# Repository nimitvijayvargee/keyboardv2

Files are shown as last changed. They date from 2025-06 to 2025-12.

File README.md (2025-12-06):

# keyboardv2

A second version of my original keyboard I designed during Hackpad V2. This keyboard follows a slight variation of the ANSI-75 Layout and is coded with QMK and and customizable with VIAL.
The keyboard deviates from my original design by implementing RGB and embracing the plate-less design. The keyboard has per-key RGB thanks to the SK6812-Mini-e Inverted LED.


## Keyboard in VIAL


## Keyboard Case


## Section of keyboard routing near the microcontroller


## KLE viewer of the keyboard (ANSI-75)


## PCB Render


## All together!


# Note about the case V2 design
The new design was designed differently from the rest of the keyboard for Blueprint. It fixes some of my issues with the previous design, mainly the size and the thickness. This design is a bit more fragile, but unless you absolutely destroy your keyboard at 400WPM, it should hold. The USB port design is also slightly tighter, but unless you are using a USB cable thicker than the MCU itself, you should be fine. The other changes are the screw holes having chamfering to prevent snapping off under pressure, and the tolerances being increased to be 3D printed better.

# Bill of Materials (for highway)
| Item | Cost(INR) | Cost(USD) |
|---|---|---|
| PCBA | 6460 | 75 |
| Switches | 2800 | 33 |
| Keycaps | 1300 | 15 |
| Rotary Encoder, Threaded Inserts, M3x6 Screws, Adhesive Grips | 1500 | 18 |
| Stabilizers | 1000 | 13 |
| Case (Printing Legion) | N/A | N/A |
| **Total** | **12060** | **154** |

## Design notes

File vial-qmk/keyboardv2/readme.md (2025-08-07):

# nimits_keyboard_v2

Developed by Nimit Vijayvargee and funded by Hack Club!

* Keyboard Maintainer: [Nimit Vijayvargee](https://github.com/NimitVijayvargee)
* Hardware Supported: RP2040 boards that follow the Pi Pico footprint (i.e Raspberry Pi Pico, Pico H or Pico W/WH)
* Hardware Availability: [Raspberry Pi](https://www.raspberrypi.com/products/raspberry-pi-pico/)

## Bootloader

Enter the bootloader by holding "BOOTSEL" while connecting the device. The device is now in bootloader mode.

## Flashing

After entering bootloader mode, copy and paste generated .uf2 (binary) file into USB Mass storage drive labelled "RPI-RP2". The device will now reconnect with the newly flashed firmware.

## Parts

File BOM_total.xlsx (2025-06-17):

Product/Item | Source | Price (INR) | Price (USD) | Required for | Comment
PCB + Assembly | JLCPCB | N/A | 75 | Main Keyboard | The PCB, you can't build a keyboard without this
Akko V3 Silver Switch (45x2) | Stackskb | 2800 | 32.73 | Switches | Personal Preference, decently priced at 36c/pc.
Keycaps | Stackskb | 1300 | 15.2 | Keycaps | Generic gradient keycaps in white-blue, cherry layout
EC11 Rotary Encoder | Amazon | 1500 | 18 | Encoder | Knob for volume control
M3x6 Threaded Inserts |  |  |  | Mounting | Will be melted into the plastic with my handy soldering iron
Allen style M3x6 Screws |  |  |  | Mounting | Quantity is 300, but lower quantity is more expensive somehow
Grips for case |  |  |  |  | Anti slip adhesive grips to apply to the back of the plastic
Stabilizers | Meckeys | 1000 | 13 | Stabilizers | PCB Mounted
Case | Printing Legion | N/A | N/A | Casing | 3D printed
Total |  |  | 153.93

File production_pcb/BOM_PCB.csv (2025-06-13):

Designator | Qty | Value | DNP | LCSC Part # | Comment | Footprint
A1 | 1 | RaspberryPi_Pico | DNP |  |  | Module:RaspberryPi_Pico_Common_Unspecified
C1,C2,C3,C4,C5,C6,C7,C8,C9,C10,C11,C12,C13,C14,C15,C16,C17,C18,C19,C20,C21,C22,C23,C24,C25,C26,C27,C28,C29,C30,C31,C32,C33,C34,C35,C36,C37,C38,C39,C40,C41,C42,C43,C44,C45,C46,C47,C48,C49,C50,C51,C52,C53,C54,C55,C56,C57,C58,C59,C60,C61,C62,C63,C64,C65,C66,C67,C68,C69,C70,C71,C72,C73,C74,C75,C76,C77,C78,C79,C80 | 80 | 100nF |  | C344189 | 100nF | Capacitor_SMD:C_0402_1005Metric
D1,D3,D4,D5,D6,D7,D8,D9,D10,D12,D13,D14,D15,D16,D17,D18,D19,D20,D21,D22,D23,D24,D25,D26,D27,D28,D29,D30,D32,D33,D34,D35,D36,D37,D38,D39,D40,D41,D42,D43,D44,D45,D46,D48,D49,D50,D51,D52,D53,D54,D55,D56,D57,D58,D59,D60,D62,D64,D65,D66,D67,D68,D69,D70,D71,D72,D73,D74,D75,D77,D80,D81,D82,D83,D84,D85,D87,D88,D89,D93,D94,D96 | 82 | Diode |  | C917030 | 1N4148 | Diode_SMD:D_SOD-123
D97,D99,D100,D101,D102,D103,D104,D105,D106,D108,D109,D110,D111,D113,D114,D115,D116,D117,D118,D119,D120,D121,D122,D123,D124,D125,D126,D128,D129,D130,D131,D132,D133,D134,D135,D136,D137,D138,D139,D140,D141,D142,D144,D145,D146,D147,D148,D149,D150,D151,D152,D153,D154,D155,D156,D158,D160,D161,D162,D163,D164,D165,D166,D167,D168,D169,D170,D171,D173,D176,D177,D178,D179,D180,D183,D184,D185,D189,D190,D192 | 80 | LED_SK6812MINI |  | C5149201 | RGB_LED | SK6812:LED_SK6812-E
H1,H2,H3 | 3 | Mounting_Hole | DNP |  |  | ScottoKeebs_Stabilizer:Stabilizer_MX_2.00u
H4 | 1 | Mounting_Hole | DNP |  |  | ScottoKeebs_Stabilizer:Stabilizer_MX_6.25u
H5,H6,H7,H8,H9 | 5 | Mounting_Hole | DNP |  |  | MountingHole:MountingHole_3.2mm_M3
S1,S3,S4,S5,S6,S7,S8,S9,S10,S12,S13,S14,S15,S17,S18,S19,S20,S21,S22,S23,S24,S25,S26,S27,S28,S29,S32,S34,S35,S36,S37,S38,S39,S40,S41,S42,S43,S44,S45,S48,S50,S51,S52,S53,S54,S55,S56,S57,S58,S59,S60,S64,S66,S67,S68,S69,S70,S71,S72,S73,S74,S75,S80,S89,S93,S94,S96 | 67 | Keyswitch | DNP |  |  | ScottoKeebs_MX:MX_PCB_1.00u
S30 | 1 | Keyswitch | DNP |  |  | ScottoKeebs_MX:MX_PCB_2.00u
S33,S46 | 2 | Keyswitch | DNP |  |  | ScottoKeebs_MX:MX_PCB_1.50u
S49,S77 | 2 | Keyswitch | DNP |  |  | ScottoKeebs_MX:MX_PCB_1.75u
S62,S65 | 2 | Keyswitch | DNP |  |  | ScottoKeebs_MX:MX_PCB_2.25u
S81,S82,S83,S87,S88 | 5 | Keyswitch | DNP |  |  | ScottoKeebs_MX:MX_PCB_1.25u
S84 | 1 | Keyswitch | DNP |  |  | ScottoKeebs_MX:MX_PCB_6.25u
SW1 | 1 | RotaryEncoder_Switch_MP | DNP |  |  | Rotary_Encoder:RotaryEncoder_Alps_EC11E-Switch_Vertical_H20mm_MountingHoles

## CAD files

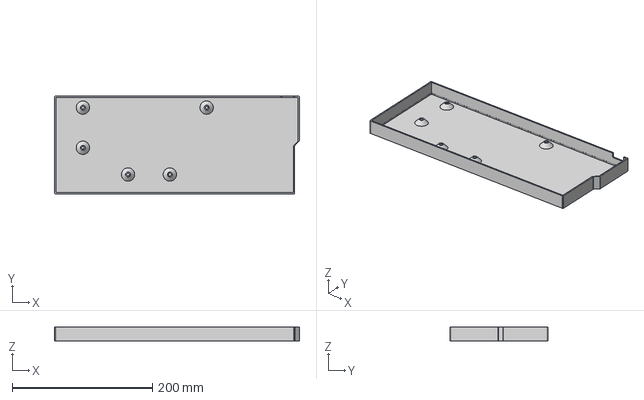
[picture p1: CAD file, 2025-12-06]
CAD/casev2.step
348.9 x 139.0 x 20.0 mm

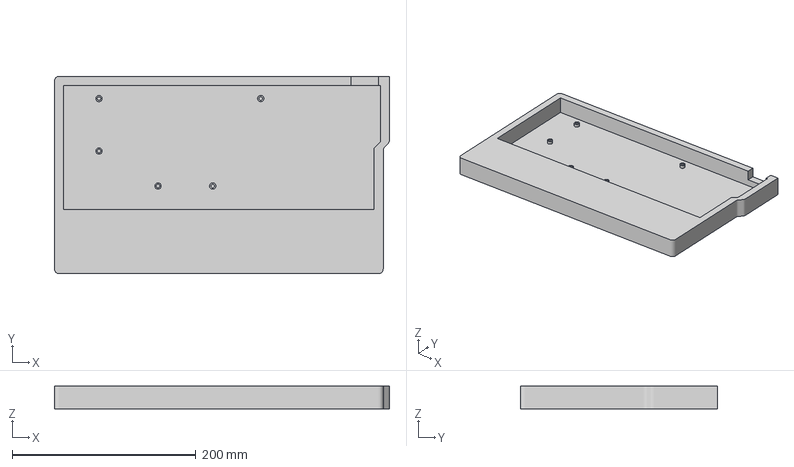
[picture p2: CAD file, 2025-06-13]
CAD/Case.3mf
364.9 x 215.0 x 25.0 mm

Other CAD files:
CAD/Case.obj
CAD/Case.stl

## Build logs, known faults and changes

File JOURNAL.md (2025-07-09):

---
title: "Nimit's Keyboard V2"
author: "Nimit Vijayvargee"
description: "A QMK supporting keyboard built around the RP2040"
created_at: "2025-05-22"
---

# May 22
Time Spent: 2 Hours <br>
Made a schematic of the keyboard and also laid out all the components into the PCB editor. Did research on the parts and components and am preparing for the Bill of Materials.




# May 26
Time Spent: 1 Hour <br>
Re-routing the PCB so that I can include a ground plane. Also improved the schematic by flipping LEDs in alternate rows to decrease routing issues.



# May 27 - June 5th
Time Spent: 6 Hours <br>
Polishing the PCB. Also added decoupling resistors according to the PCB Spec. Fixed electrical issues and began setting up my QMK environment to work on the firmware.
Compared prices and conducted research on components across manufacturers. Finalized PCBA and component settings in JLCPCB



# June 6th - June 11th
Time Spent: 3 Hours <br>
Completed PCB, created KLE layout (for future porting to VIAL) and setup configs for QMK. Also made the Case sketch



# June 12th 
Time Spent: 2 Hours <br>
Completed case (extrusion), compared prices and created BOM list. Case is left to export. After this, I will only need to finish setting up the QMK definitions to work with the LEDs and the rotary encoders.


# June 13th
Time Spent: 1 Hour <br>
Exported Case files into printable 3D models. Commited local project files from KiCad and Fusion to github.
Also started working on polishing QMK to work with the LEDs.

# June 14th
Time Spent: 2 Hour <br>
Took a break from QMK and started working on the VIAL configs instead. Successfully loaded keyboard into VIAL editor.
Readied the project for submission!


# June 18th - June 19th
Time Spent: 1 Hour <br>
Added silkscreen art, worked on QMK configs.


# July 4th - July 5th
Time Spent: 8 Hours <br>
The PCBs arrived! I spent more than 4 hours each day to solder them, test connections and resolder them! My soldering skills weren't that good and left a lot to be desired but it ended up working out! I also a burnt a pad for one of the switches (oops) so I had to solder a copper wire between that pad and the diode but oops!



# July 5th - July 7th
Time Spent: 7 Hours <br>
Getting QMK to compile with the RGB Features! It took a lot of trial and error and it was very annoying to get it working. I also worked on getting vial worked out at the same time! It was kind of difficult since I am more used to python but adding all my features in info.json worked without any actual code so that was kind of nice.
I also had to do a bit of troubleshooting on the solder joints because they were bugging the matrix by shorting ground.


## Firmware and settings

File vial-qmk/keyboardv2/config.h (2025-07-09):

#pragma once 
#define ENABLE_RGB_MATRIX_ALPHAS_MODS               // Enables RGB_MATRIX_ALPHAS_MODS
#define ENABLE_RGB_MATRIX_GRADIENT_UP_DOWN          // Enables RGB_MATRIX_GRADIENT_UP_DOWN
#define ENABLE_RGB_MATRIX_GRADIENT_LEFT_RIGHT       // Enables RGB_MATRIX_GRADIENT_LEFT_RIGHT
#define ENABLE_RGB_MATRIX_BREATHING                 // Enables RGB_MATRIX_BREATHING
#define ENABLE_RGB_MATRIX_BAND_SAT                  // Enables RGB_MATRIX_BAND_SAT
#define ENABLE_RGB_MATRIX_BAND_VAL                  // Enables RGB_MATRIX_BAND_VAL
#define ENABLE_RGB_MATRIX_BAND_PINWHEEL_SAT         // Enables RGB_MATRIX_BAND_PINWHEEL_SAT
#define ENABLE_RGB_MATRIX_BAND_PINWHEEL_VAL         // Enables RGB_MATRIX_BAND_PINWHEEL_VAL
#define ENABLE_RGB_MATRIX_BAND_SPIRAL_SAT           // Enables RGB_MATRIX_BAND_SPIRAL_SAT
#define ENABLE_RGB_MATRIX_BAND_SPIRAL_VAL           // Enables RGB_MATRIX_BAND_SPIRAL_VAL
#define ENABLE_RGB_MATRIX_CYCLE_ALL                 // Enables RGB_MATRIX_CYCLE_ALL
#define ENABLE_RGB_MATRIX_CYCLE_LEFT_RIGHT          // Enables RGB_MATRIX_CYCLE_LEFT_RIGHT
#define ENABLE_RGB_MATRIX_CYCLE_UP_DOWN             // Enables RGB_MATRIX_CYCLE_UP_DOWN
#define ENABLE_RGB_MATRIX_RAINBOW_MOVING_CHEVRON    // Enables RGB_MATRIX_RAINBOW_MOVING_CHEVRON
#define ENABLE_RGB_MATRIX_CYCLE_OUT_IN              // Enables RGB_MATRIX_CYCLE_OUT_IN
#define ENABLE_RGB_MATRIX_CYCLE_OUT_IN_DUAL         // Enables RGB_MATRIX_CYCLE_OUT_IN_DUAL
#define ENABLE_RGB_MATRIX_CYCLE_PINWHEEL            // Enables RGB_MATRIX_CYCLE_PINWHEEL
#define ENABLE_RGB_MATRIX_CYCLE_SPIRAL              // Enables RGB_MATRIX_CYCLE_SPIRAL
#define ENABLE_RGB_MATRIX_DUAL_BEACON               // Enables RGB_MATRIX_DUAL_BEACON
#define ENABLE_RGB_MATRIX_RAINBOW_BEACON            // Enables RGB_MATRIX_RAINBOW_BEACON
#define ENABLE_RGB_MATRIX_RAINBOW_PINWHEELS         // Enables RGB_MATRIX_RAINBOW_PINWHEELS
#define ENABLE_RGB_MATRIX_FLOWER_BLOOMING           // Enables RGB_MATRIX_FLOWER_BLOOMING
#define ENABLE_RGB_MATRIX_RAINDROPS                 // Enables RGB_MATRIX_RAINDROPS
#define ENABLE_RGB_MATRIX_JELLYBEAN_RAINDROPS       // Enables RGB_MATRIX_JELLYBEAN_RAINDROPS
#define ENABLE_RGB_MATRIX_HUE_BREATHING             // Enables RGB_MATRIX_HUE_BREATHING
#define ENABLE_RGB_MATRIX_HUE_PENDULUM              // Enables RGB_MATRIX_HUE_PENDULUM
#define ENABLE_RGB_MATRIX_HUE_WAVE                  // Enables RGB_MATRIX_HUE_WAVE
#define ENABLE_RGB_MATRIX_PIXEL_FRACTAL             // Enables RGB_MATRIX_PIXEL_FRACTAL
#define ENABLE_RGB_MATRIX_PIXEL_FLOW                // Enables RGB_MATRIX_PIXEL_FLOW
#define ENABLE_RGB_MATRIX_PIXEL_RAIN                // Enables RGB_MATRIX_PIXEL_RAIN
#define ENABLE_RGB_MATRIX_STARLIGHT                 // Enables RGB_MATRIX_STARLIGHT
#define ENABLE_RGB_MATRIX_STARLIGHT_SMOOTH          // Enables RGB_MATRIX_STARLIGHT_SMOOTH
#define ENABLE_RGB_MATRIX_STARLIGHT_DUAL_HUE        // Enables RGB_MATRIX_STARLIGHT_DUAL_HUE
#define ENABLE_RGB_MATRIX_STARLIGHT_DUAL_SAT        // Enables RGB_MATRIX_STARLIGHT_DUAL_SAT
#define ENABLE_RGB_MATRIX_RIVERFLOW                 // Enables RGB_MATRIX_RIVERFLOW
#define ENABLE_RGB_MATRIX_SOLID_REACTIVE_SIMPLE     // Enables RGB_MATRIX_SOLID_REACTIVE_SIMPLE
#define ENABLE_RGB_MATRIX_SOLID_REACTIVE            // Enables RGB_MATRIX_SOLID_REACTIVE
#define ENABLE_RGB_MATRIX_SOLID_REACTIVE_WIDE       // Enables RGB_MATRIX_SOLID_REACTIVE_WIDE
#define ENABLE_RGB_MATRIX_SOLID_REACTIVE_MULTIWIDE  // Enables RGB_MATRIX_SOLID_REACTIVE_MULTIWIDE
#define ENABLE_RGB_MATRIX_SOLID_REACTIVE_CROSS      // Enables RGB_MATRIX_SOLID_REACTIVE_CROSS
#define ENABLE_RGB_MATRIX_SOLID_REACTIVE_MULTICROSS // Enables RGB_MATRIX_SOLID_REACTIVE_MULTICROSS
#define ENABLE_RGB_MATRIX_SOLID_REACTIVE_NEXUS      // Enables RGB_MATRIX_SOLID_REACTIVE_NEXUS
#define ENABLE_RGB_MATRIX_SOLID_REACTIVE_MULTINEXUS // Enables RGB_MATRIX_SOLID_REACTIVE_MULTINEXUS
#define ENABLE_RGB_MATRIX_SPLASH                    // Enables RGB_MATRIX_SPLASH
#define ENABLE_RGB_MATRIX_MULTISPLASH               // Enables RGB_MATRIX_MULTISPLASH
#define ENABLE_RGB_MATRIX_SOLID_SPLASH              // Enables RGB_MATRIX_SOLID_SPLASH
#define ENABLE_RGB_MATRIX_SOLID_MULTISPLASH         // Enables RGB_MATRIX_SOLID_MULTISPLASH
#define ENABLE_RGB_MATRIX_TYPING_HEATMAP            // Enables RGB_MATRIX_TYPING_HEATMAP
#define ENABLE_RGB_MATRIX_DIGITAL_RAIN              // Enables RGB_MATRIX_DIGITAL_RAIN

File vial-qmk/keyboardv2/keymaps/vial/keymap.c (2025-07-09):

// Copyright 2023 QMK
// SPDX-License-Identifier: GPL-2.0-or-later

#include QMK_KEYBOARD_H

const uint16_t PROGMEM keymaps[][MATRIX_ROWS][MATRIX_COLS] = {

    [0] = LAYOUT_75_ansi(
        KC_ESC, KC_F1, KC_F2, KC_F3, KC_F4, KC_F5, KC_F6, KC_F7, KC_F8, KC_F9, KC_F10, KC_F11, KC_F12, KC_MPLY,
        KC_GRV, KC_1, KC_2, KC_3, KC_4, KC_5, KC_6, KC_7, KC_8, KC_9, KC_0, KC_MINS, KC_EQL, KC_BSPC, KC_DEL,
        KC_TAB, KC_Q, KC_W, KC_E, KC_R, KC_T, KC_Y, KC_U, KC_I, KC_O, KC_P, KC_LBRC, KC_RBRC, KC_BSLS, KC_PGUP,
        KC_CAPS, KC_A, KC_S, KC_D, KC_F, KC_G, KC_H, KC_J, KC_K, KC_L, KC_SCLN, KC_QUOT, KC_ENT, KC_PGDN,
        KC_LSFT, KC_Z, KC_X, KC_C, KC_V, KC_B, KC_N, KC_M, KC_COMM, KC_DOT, KC_SLSH, KC_RSFT, KC_END,
        KC_LCTL, KC_LGUI, KC_LALT, KC_SPC, KC_RALT, KC_RCTL, KC_LEFT, KC_DOWN, KC_RIGHT, KC_UP
    )

};

#if defined(ENCODER_MAP_ENABLE)
const uint16_t PROGMEM encoder_map[][NUM_ENCODERS][NUM_DIRECTIONS] = {
    [0] = { ENCODER_CCW_CW(KC_MPRV, KC_MNXT)  },
};  
#endif
    

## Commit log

2025-06-13 Added PCB, CAD and production files
    [BOM_PCB.csv, BOM_total.xlsx, Case.3mf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]
2025-06-14 fix spelin
    [BOM_total.xlsx]
2025-06-17 Fixed Fatal Flaw in RGB LED Data Line, Updated BOM
    [BOM_total.xlsx, keyboardv2.kicad_sch]
2025-06-19 Add Silkscreen :D
2025-06-19 Update PCB Render
